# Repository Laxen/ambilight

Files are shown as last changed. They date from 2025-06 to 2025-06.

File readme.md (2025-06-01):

### ESP32
* The ESP32-C3-MINI boards expose USB and have really good documentation
* ESP32 is generally cheaper and better than ESP8266 (faster CPU, BLE, more RAM/flash), and ESP8266 is not recommended for new designs
* The ESP32-WROOM boards don't expose the USB interface of the ESP32, which would then require an additional USB-to-UART component adding cost
* TODO: In the datasheet it says "USB Serial/JTAG Controller can also force the chip into Joint Download Boot mode from SPI Boot mode, as well as force the chip into SPI Boot mode from Joint Download Boot mode. For detailed information, please refer to Chapter 30 USB Serial/JTAG Controller (USB_SERIAL_JTAG).", can this be used to avoid buttons entirely? It would cut costs and make the device easier to use.

### USB-C Connector
* TYPE-C-31-M-12, provides USB 2.0 data lines in an easy-to-manufacture package

### ESD Protection
* USBLC6-2, common component specifically designed for USB 2.0
* Layout optimized to be close to USB-C connector, and have short traces for data and VBUS/GND
* 100nF between VBUS and GND was missed, but there's one not far away for the LDO which should be sufficient

### Level Shifter
* MCP1416, common component in a small package, enough current output for longer LED strip data lines
* ~SN74LVC1T45DBVR, only has 24mA output current, might not be enough for longer LED strip data lines~

### LDO
* AZ1117-3.3, common component, low enough dropout for 5V -> 3.3V, high enough current for ESP32, modern design that is compatible with low ESR ceramic caps
* ~AMS1117-3.3, common component, low enough dropout for 5V -> 3.3V, high enough current for ESP32, however it requires a tantalum cap on the output which is annoying~

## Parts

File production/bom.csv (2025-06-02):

Designator | Footprint | Quantity | Value | LCSC Part #
C1, C5 | 0805 | 2 | 10uF
C2 | 0805 | 1 | 22uF
C3, C9 | 0805 | 2 | 1uF
C4, C8 | 0805 | 2 | 0.1uF
D1 | 0805 | 1 | LED
J1 | USB_C_Receptacle_HRO_TYPE-C-31-M-12 | 1 | TYPE-C-31-M-12
J2 | PinHeader_1x03_P2.54mm_Vertical | 1 | RGB Connector | C49257
J3 | PinHeader_1x03_P2.54mm_Vertical | 1 | Power Connector | C49257
R1, R2 | 0805 | 2 | 5.1k
R3 | 0805 | 1 | 330R
R4, R5, R6 | 0805 | 3 | 10k
R7, R8 | 0805 | 2 | 0R
SW1 | TS-1088-AR02016 | 1 | RESET | C720477
SW2 | TS-1088-AR02016 | 1 | BOOT | C720477
U1 | SOT-223-3_TabPin2 | 1 | AZ1117CH-3.3TRG1
U2 | SOT-23-6 | 1 | USBLC6-2SC6
U3 | ESP32-C3-MINI-1 | 1 | ESP32-C3-MINI-1-H4 | C41349510
U4 | SOT-23-5 | 1 | MCP1416

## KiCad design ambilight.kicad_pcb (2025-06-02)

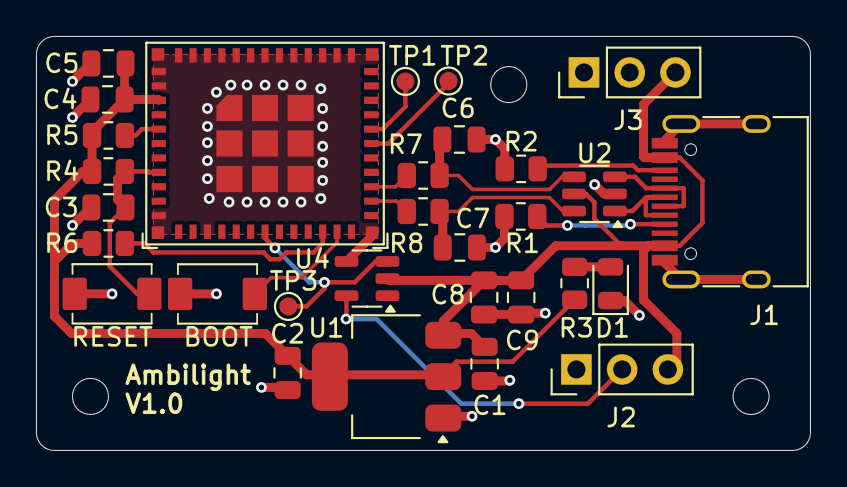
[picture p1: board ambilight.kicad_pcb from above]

Board: 2 copper layers, 43.0 x 23.0 mm, 30 parts (0 on the bottom side), 20 nets.

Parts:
C1, C5: 10uF; C_0805_2012Metric
C2: 22uF; C_0805_2012Metric
C3, C9: 1uF; C_0805_2012Metric
C4, C8: 0.1uF; C_0805_2012Metric
C6, C7: TBD; C_0805_2012Metric
D1: LED; LED_0805_2012Metric
J1: TYPE-C-31-M-12; USB_C_Receptacle_HRO_TYPE-C-31-M-12
J2: RGB Connector; PinHeader_1x03_P2.54mm_Vertical
J3: Power Connector; PinHeader_1x03_P2.54mm_Vertical
R1, R2: 5.1k; R_0805_2012Metric
R3: 330R; R_0805_2012Metric
R4, R5, R6: 10k; R_0805_2012Metric
R7, R8: 0R; R_0805_2012Metric
SW1: RESET; TS-1088-AR02016
SW2: BOOT; TS-1088-AR02016
TP1, TP2, TP3: TestPoint_Pad_D1.0mm_SilkscreenFix
U1: AZ1117CH-3.3TRG1; SOT-223-3_TabPin2
U2: USBLC6-2SC6; SOT-23-6
U3: ESP32-C3-MINI-1-H4; ESP32-C3-MINI-1
U4: MCP1416; SOT-23-5

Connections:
+3V3: C2.1, C4.1, C5.1, R3.1, R4.1, R5.2, R6.2, U1.2 (VO), U3.3 (3V3)
/D+: R7.1, U3.27 (GPIO19/USB_D+)
/D-: R8.1, U3.26 (GPIO18/USB_D-)
/USBD+: C6.1, R7.2, U2.4 (I/O2)
/USBD-: C7.1, R8.2, U2.6 (I/O1)
GND: C1.2, C2.2, C3.2, C4.2, C5.2, C6.2, C7.2, C8.2, C9.2, D1.1 (K), J1.A1 (GND), J1.A12 (GND), J1.B1 (GND), J1.B12 (GND), J1.S1 (SHIELD), J2.1, J3.1, R1.2, R2.2, SW1.2, SW2.2, U1.1 (GND), U2.2 (GND), U3.1 (GND), U3.2 (GND), U3.11 (GND), U3.14 (GND), U3.36 (GND), U3.37 (GND), U3.38 (GND), U3.39 (GND), U3.40 (GND), U3.41 (GND), U3.42 (GND), U3.43 (GND), U3.44 (GND), U3.45 (GND), U3.46 (GND), U3.47 (GND), U3.48 (GND), U3.49 (GND), U3.50 (GND), U3.51 (GND), U3.52 (GND), U3.53 (GND), U4.4 (GND)
unnamed: D1.2 (A), R3.2
unnamed: J1.A5 (CC1), R1.1
unnamed: J1.B5 (CC2), R2.1
unnamed: J1.A6 (D+), J1.B6 (D+), U2.3 (I/O2)
unnamed: J1.A7 (D-), J1.B7 (D-), U2.1 (I/O1)
unnamed: J2.2, U4.5 (OUT)
unnamed: C3.1, R4.2, SW1.1, U3.8 (EN/CHIP_PU)
unnamed: R5.1, U3.5 (GPIO2/ADC1_CH2)
unnamed: TP3.1, U3.18 (GPIO4/ADC1_CH4), U4.3 (IN)
unnamed: R6.1, U3.22 (GPIO8)
unnamed: SW2.1, U3.23 (GPIO9)
unnamed: TP2.1, U3.30 (GPIO20/U0RXD)
unnamed: TP1.1, U3.31 (GPIO21/U0TXD)
VCC: C1.1, C8.1, C9.1, J1.A4 (VBUS), J1.A9 (VBUS), J1.B4 (VBUS), J1.B9 (VBUS), J2.3, J3.3, U1.3 (VI), U2.5 (VBUS), U4.2 (Vdd)

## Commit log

2025-05-22 Initial commit
    Bit of a mess, some detail work for USB4085 -> FT230XS but not completed
    yet.
    [ambilight.kicad_pcb, ambilight.kicad_sch]
2025-05-24 Work on USB-C, FT230XS and LDO
    [ambilight.kicad_sch]
2025-05-24 Use ESP32 instead, add readme
    The ESP32 makes a lot more sense in this application. The readme is very
    basic and will be used for explaining component choices, among other
    things in the future.
    [ambilight.kicad_sch]
2025-05-27 Bunch of updates and beginning of PCB layout
    [ambilight.kicad_pcb, ambilight.kicad_sch]
2025-05-28 First draft of layout
    [ambilight.kicad_pcb]
2025-05-28 Some reordering
    [ambilight.kicad_pcb]
2025-05-28 Add ESD protection, reroute layout more efficiently
    [ambilight.kicad_pcb, ambilight.kicad_sch]
2025-06-02 Minor layout adjustments
    [ambilight.kicad_pcb, ambilight.kicad_sch]
2025-06-02 Fix resistor values
    [ambilight.kicad_pcb, ambilight.kicad_sch]
2025-06-02 Many small-ish changes, generate production files
    Some components were changed to get better deal at manufacturer. The
    files in the production folder are the ones sent to the manufacturer for
    this release.
    [ambilight.kicad_pcb, ambilight.kicad_sch, bom.csv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]
